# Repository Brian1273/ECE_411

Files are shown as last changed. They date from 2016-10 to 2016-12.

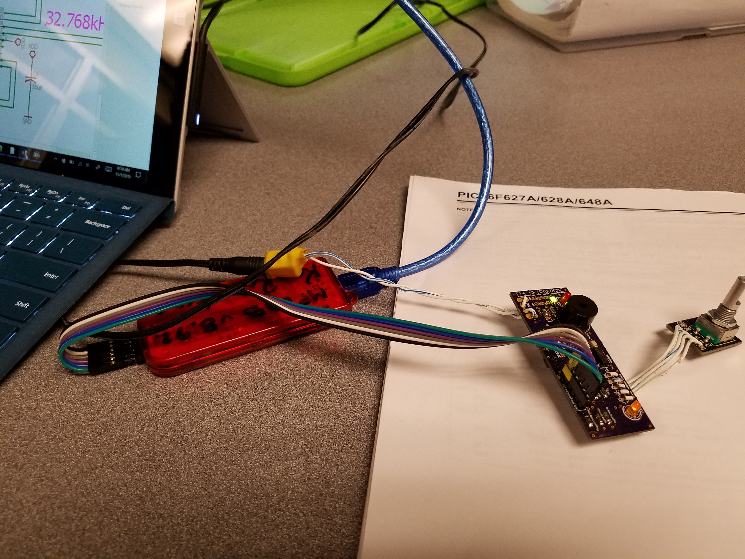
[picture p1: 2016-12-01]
Project_Metronome/Images/Progress_Images/test_debug.jpg

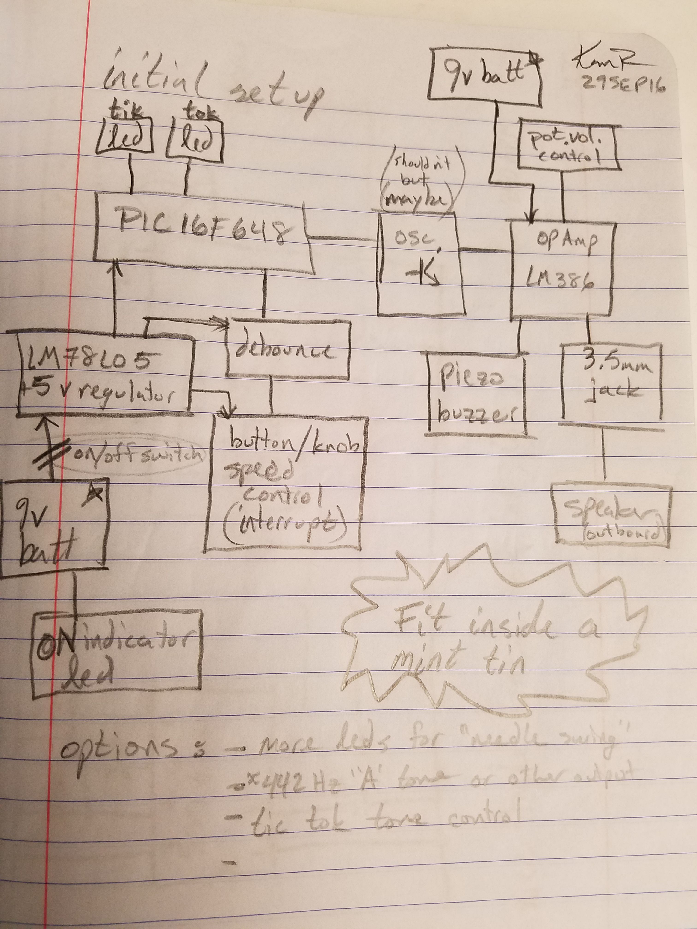
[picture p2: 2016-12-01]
Project_Metronome/Images/Progress_Images/block_diagram_concept.jpg

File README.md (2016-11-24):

# ECE_411

ECE411 practicum project:  Metronome.

Objectives:

Use an input device such as a sensor
Use an output device such as an LED or sound emitter
Use a microcontroller to manager the signals.

All of these items are combined to create a metronome that is capable of pace setting and provides visual and auditory feedback.

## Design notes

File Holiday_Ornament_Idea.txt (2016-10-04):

Kam Robertson
October 2016
Holiday Ornament or Trinket

What holiday is complete without a theme shaped pcb with flahing lights and a piezo soundtrack?

Use the microcontroller to flash as many led's as posible on a 9v battery in several pleasing 
themes and play lovely piezo electric music to match.
Add a safety pin and it is a perfect complement to the madatory sweater!

This is the perfect cliche holiday project.

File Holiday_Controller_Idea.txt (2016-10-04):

Kam Robertson
October 2016
Holiday Light Controller

Use a microcontroller to control a relay that controls power to a holiday string lighting.
Use a conventional plug strip and some metal seperation inside for the low voltage.
Input a signal to the microcontroller via a debounced dc switch to select the theme.
Output the signals to several transistors controlling several 5vdc 120vac 2amp relays (optocoupler?)
The controller will then turn the relays on and off in several pleasing themes.
Allow for manual shut down with the power off switch on the plug strip
Provide power to the contoller and support hardware from 120vac

I don't have a good small circuit worked out that has been tested to provide usable power from 120vac
May need to use a pre-packaged power supply.

This would be a nice practical holiday project.

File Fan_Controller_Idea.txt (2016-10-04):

Kam Robertson
October 2016
Bathroom Fan Controller

Use a microcontroller to control a relay that controlls power to a bathroom fart fan.
Input a signal to the microcontroller via a conventional 120v light switch (optocoupler)
Output the signal to a transistor controlling the 5vdc 120vac 2amp relay (optocoupler?)
The controller will then turn on the relay and begin a 20-30 minute countdown 
to shut off of the relay and fan.  then do so.
Allow for manual shut down of the relay via a second cyling of the light switch.
Provide power to the contoller and support hardware from 120vac
Put the whole thing on a tiny pcb with some led's to indicate life and labeled 14gauge wires hanging out
Package it with nice thick adhesive shrink tube. (1000v rated)

This would be a nice practical project that is installable and invisible in existing construction.
I want at least several and know at least one other person who doea too!

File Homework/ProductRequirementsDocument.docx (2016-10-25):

Product Requirements Document

Project MetroKnome

Revision Date: 10/24/2016

Team #: 14

Team Members:

Saly Hakkoum

Kam Robertson

Brian Dunn

Kyle Johnson

A. Purpose/summary

Visual and aural output variable timing device that can be used as a baseline for a specific pace.

B. Needs/objective/background:

Inexpensive solution to provide a pace setting device for a multitude of uses that incorporates an input mechanism to set the desired pace along with an output mechanism to confirm the desired pace.

Minimal instructions necessary beyond product description, easy to use such that a 5 year old human child can operate within 1 minute.

C. Functionality

Input device to change the pace (beats per minute).

Output device to produce auditory indicator of the passage of the set time period.

Output device to produce visual indicator of passage of the set time period.

Programmable.

D. Performance

30 to 230 bpm in 20 beat increments to provide a variety of slow, medium, and fast tempos.

E. Competition/Intended Market

Competition is substantial, therefore a low cost solution is needed.

The primary market is musicians for time synchronization, however the device will enable anyone needing a visual/aural pace setting device. An example includes medical training centers who use the device to optimize the timing of chest compressions during cardiopulmonary resuscitation on a manikin.

F. Safety/Environmental

Intrinsically safe, dry, at room temperature.

G. Economic

The total parts and manufacturing costs cannot exceed $50 per unit

The development costs should not exceed $250

H. Energy

The system will use an off the shelf 9V battery.

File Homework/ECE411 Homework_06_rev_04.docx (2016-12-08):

ECE411 Homework_6

Test Plan, Revision 2.0

November 23, 2016

Team#14

Kam Robertson

Saly Hakkoum

Brian Dunn

Kyle Johnson

## Introduction

We have designed a metronome to satisfy the practicum requirements of an input device, output device, and microcontroller.

We define metronome as a pace setting device that provides an aural and visual indictor of pace.

A formal definition:

“a mechanical or electrical instrument that makes repeated clicking sounds at an adjustable pace, used for marking rhythm, especially in practicing music.” [1]

To test this, the focus is on the actuators to verify the device is performing the designed function.

## Pretest preparation

1. Ohm board to verify as built assembly meets requirements for system testing.
2. Ensure board has 9V battery installed.

## Test equipment / Test setup and calibration

1. Human of average intelligence, physique, hearing, visual acuity.
2. Multi-meter to perform Ohm test
3. 9V battery

## Systems Test

### Test Case 01 Description

Verify on/off (toggle) switch work, ie does the button turn the device on/off.

### Test Case 01

| Test Writer | Team#14 (Kyle Johnson, Kam Robertson, Saly Hakkoum, Brian Dunn)
| Test case name: | Test Case 01
| Description | Verify on/off (toggle) switch work
| Type | Black Box
| Tester Information
| Name of tester
| Hardware Version | Version 2.0
| Setup | 1. Ohm board to verify as built assembly meets requirements for system testing. 2. Ensure board has 9V battery installed.
Step | Action | Expected Results | Pass | Fail | NA | Comment
1 | Position metronome on flat surface | Device ready for visual observation.
2 | Verify device is at initial state | Observe initial state, OFF
3 | Press power button | The device changes state, visual indications such as lights turn on.
4 | Verify device is in on state | Lights turn on.
5 | Press power button | The device changes state, visual indications such as lights turn off
6 | Verify device is in off state | Lights are off

### Test Case 02 Description

Verify button changes function of metronome.

Lights (LED) flash when button pressed.

### Test Case 02

| Test Writer | Team#14 (Kyle Johnson, Kam Robertson, Saly Hakkoum, Brian Dunn)
| Test case name: | Test Case 02
| Description | Verify button changes function of device
| Type | Black Box
| Tester Information
| Name of tester
| Hardware Version | Version 2.0
| Setup | 1. Ohm board to verify as built assembly meets requirements for system testing. 2. Ensure board has 9V battery installed.
Step | Action | Expected Results | Pass | Fail | NA | Comment
1 | Position metronome on flat surface | Device ready for visual observation.
2 | Verify device is at initial state | Observe initial state, OFF
3 | Press power button | The device changes state, visual indications such as lights turn on.
4 | Verify device is in on state | Lights turn on.
5 | Press function button | Lights flash when button pressed
6 | Observe change in function | Verify function changes when button pressed

### Test Case 03 Description

Verify button changes function of device (modes)

1) Lights (LED) flash when button pressed once. Muted 4/4 time
2) Lights (LED) flash when button pressed twice in addition to sound (beep) matching up with each LED flash. 4/4 time
3) “ “ 2/4 time (BEEP,beep…)
4) “ “ 2/3 time (BEEP, beep, beep…)
5) “ “ 3/4 time (BEEP, beep, beep, beep…)
6) “ “ 6/8 time (BEEP, beep, beep, beep, beep, beep…)
7) Standby: UUT returns to idle state

### Test Case 03

| Test Writer | Team#14 (Kyle Johnson, Kam Robertson, Saly Hakkoum, Brian Dunn)
| Test case name: | Test Case 03
| Description | Verify button changes function of device (modes)
| Type | Black Box
| Tester Information
| Name of tester
| Hardware Version | Version 2.0
| Setup | 1. Ohm board to verify as built assembly meets requirements for system testing. 2. Ensure board has 9V battery installed.
Step | Action | Expected Results | Pass | Fail | NA | Comment
1 | Position metronome on flat surface | Device ready for visual observation.
2 | Verify device is at initial state | Observe initial state, OFF
3 | Press power button | The device changes state, visual indications such as lights blink once, sound occurs "beep" at initial power on
4 | Verify device is in on state | Lights blink, single beep, no additional sound, UUT idle
5 | Press function button | Lights flash when button pressed once
6 | Observe change in function | The device changes state, visual indication such as lights begin flashing in an alternating sequence (no sound) that coincides with beats per minute
7 | Press function button | Verify function changes when button pressed
8 | Observe change in function | The device changes state, visual indication such as lights begin alternating sequence along with sound to accompany each light flash that coincides with beats per minute
9 | Press function button | Verify function changes when button pressed
10 | Observe change in function | The device changes state, visual indication such as lights begin alternating sequence along with sound to accompany each light flash that coincides with beats per minute
11 | Press function button | Verify function changes when button pressed
12 | Observe change in function | The device changes state, visual indication such as lights begin alternating sequence along with sound to accompany each light flash that coincides with beats per minute
13 | Press function button | Verify function changes when button pressed
14 | Observe change in function | The device changes state, visual indication such as lights begin alternating sequence along with sound to accompany each light flash that coincides with beats per minute
15 | Press function button | Verify function changes when button pressed
16 | Observe change in function | The device changes state, visual indication such as lights begin alternating sequence along with sound to accompany each light flash that coincides with beats per minute
17 | Press function button | UUT returns to idle state
18 | Observe change in function | UUT returns to idle state, no lights, sound.

### Test Case 04 Description

Verify rotary encoder function of device

Verify UUT tempo changes (increases) with clockwise rotation of rotary encoder

Verify UUT tempo changes (decreases) with counter-clockwise rotation of rotary encoder

### Test Case 04

| Test Writer | Team#14 (Kyle Johnson, Kam Robertson, Saly Hakkoum, Brian Dunn)
| Test case name: | Test Case 03
| Description | Verify rotary encoder function of device
| Type | Black Box
| Tester Information
| Name of tester
| Hardware Version | Version 2.0
| Setup | 1. Ohm board to verify as built assembly meets requirements for system testing. 2. Ensure board has 9V battery installed.
Step | Action | Expected Results | Pass | Fail | NA | Comment
1 | Position metronome on flat surface | Device ready for visual observation.
2 | Verify device is at initial state | Observe initial state, OFF
3 | Press power button | The device changes state, visual indications such as lights blink once, sound occurs "beep" at initial power on
4 | Verify device is in on state | Lights blink, single beep, no additional sound, UUT idle
5 | Press function button | Lights flash when button pressed once
6 | Observe change in function | The device changes state, visual indication such as lights begin flashing in an alternating sequence (no sound) that coincides with beats per minute
7 | Press function button | Verify function changes when button pressed
8 | Observe change in function | The device changes state, visual indication such as lights begin alternating sequence along with sound to accompany each light flash that coincides with beats per minute
9 | Turn Rotary Encoder (clockwise) | UUT exhibits tempo increase (light sequence and sound sequence)
10 | Observe change in function | Verify UUT tempo changes (increases) with clockwise rotation of rotary encoder
11 | Turn Rotary Encoder (counter-clockwise) | UUT exhibits tempo decrease (light sequence and sound sequence)
12 | Observe change in function | Verify UUT tempo changes (decreases) with counter-clockwise rotation of rotary encoder

## Citations

1) (Dictionary.com "metronome, 2016)

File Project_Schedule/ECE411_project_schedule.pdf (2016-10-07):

ECE411_Practicum | Oct 7, 2016
PSU | http://

Project manager
Project dates | Sep 13, 2016 - Dec 9, 2016
Completion | 0%
Tasks | 14
Resources | 0

Name | Begin date | End date
Conception | 9/13/16 | 10/5/16
Teams Formed, projects analyzed | 9/13/16 | 9/19/16
Research | 9/29/16 | 10/5/16
Teams formed, project decide | 9/30/16 | 10/7/16
Parts Identification and Preliminary schematic | 10/3/16 | 10/13/16
Prototyping | 10/5/16 | 10/18/16
Preliminary Schematic | 10/17/16 | 10/21/16
Preliminary layout done | 10/24/16 | 10/25/16
Layout | 10/26/16 | 11/3/16
Board fabbed | 11/4/16 | 11/11/16
Boards to manufacturing | 11/14/16 | 11/18/16
Assembly and Test | 11/14/16 | 11/25/16
Debug | 11/14/16 | 11/25/16
Demonstrations | 11/30/16 | 12/8/16
ECE411_Practicum | Oct 7, 2016
Tasks | 2

## Gantt Chart

3

Name | Begin ... | End date
Conception | 9/13/16 10/5/16
Teams formed, project decide | 9/30/16 10/7/16

Parts Identification and Preliminary sche... 10/3/16 10/13/16

Prototyping | 10/5/16 10/18/16
Preliminary Schematic | 10/17/1610/21/16
Preliminary layout done | 10/24/1610/25/16
Layout | 10/26/1611/3/16
Board fabbed | 11/4/16 11/11/16
Boards to manufacturing | 11/14/1611/18/16
Assembly and Test | 11/14/1611/25/16
Debug | 11/14/1611/25/16
Demonstrations | 11/30/1612/8/16
October 2016 | November 2016 | December 2016
Week 41 | Week 42 | Week 43 | Week 44 | Week 45 | Week 46 | Week 47 | Week 48 | Week 49 | Week 50 | Week 51
10/2/16 | 10/9/16 | 10/16/16 | 10/23/16 | 10/30/16 | 11/6/16 | 11/13/16 | 11/20/16 | 11/27/16 | 12/4/16 | 12/11/16

## Resources Chart

4

Name | Default role
October 2016 | November 2016 | December 2016
Week 41 | Week 42 | Week 43 | Week 44 | Week 45 | Week 46 | Week 47 | Week 48 | Week 49 | Week 50 | Week 51
10/2/16 | 10/9/16 | 10/16/16 | 10/23/16 | 10/30/16 | 11/6/16 | 11/13/16 | 11/20/16 | 11/27/16 | 12/4/16 | 12/11/16

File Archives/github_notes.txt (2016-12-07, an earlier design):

After cloning repository (to remote desktop) and launching power shell (if windows based OS):

From power shell:

1.  move file to new location (mv)
2.  git add <new location>
3.  git rm <old location>
4.  git commit -m "comments"
5.  git status // last chance to make sure you got everything squared away
6.  git push

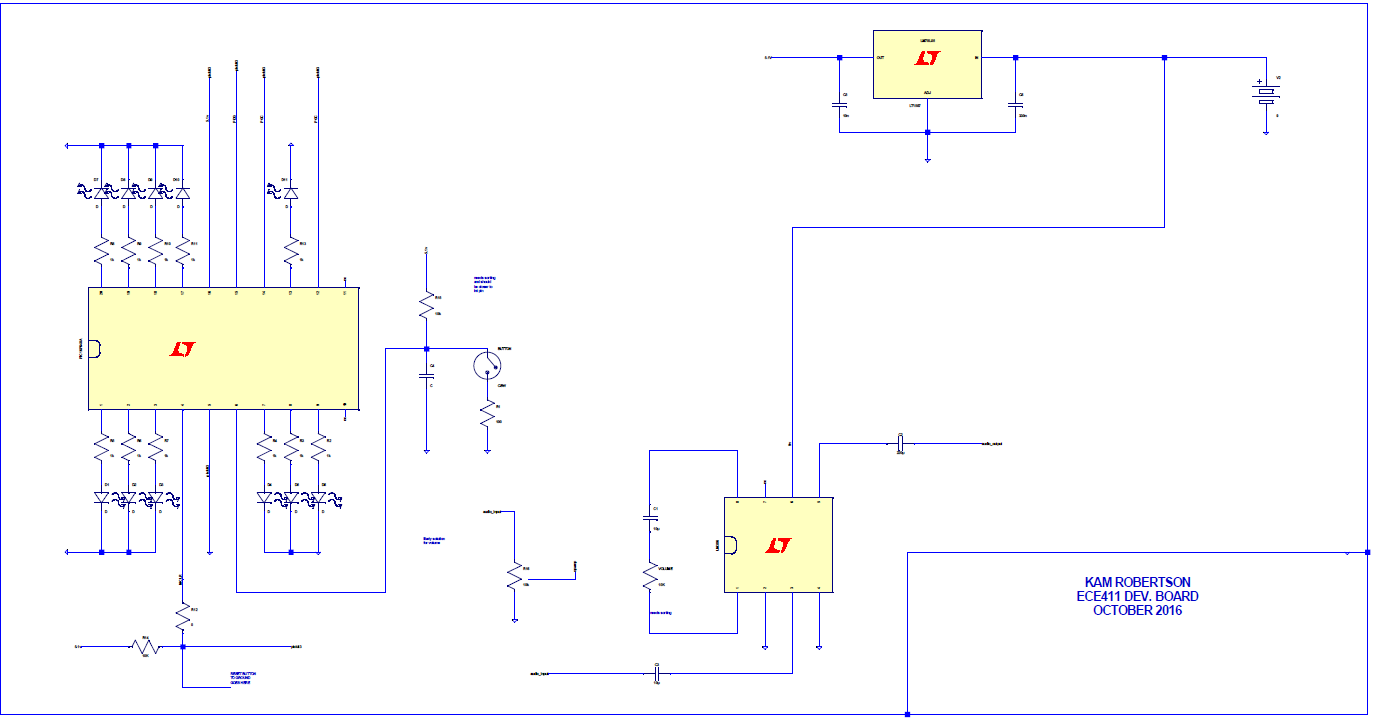
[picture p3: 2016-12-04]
Project_Metronome/Images/Progress_Images/ltspice_schematic_image.PNG

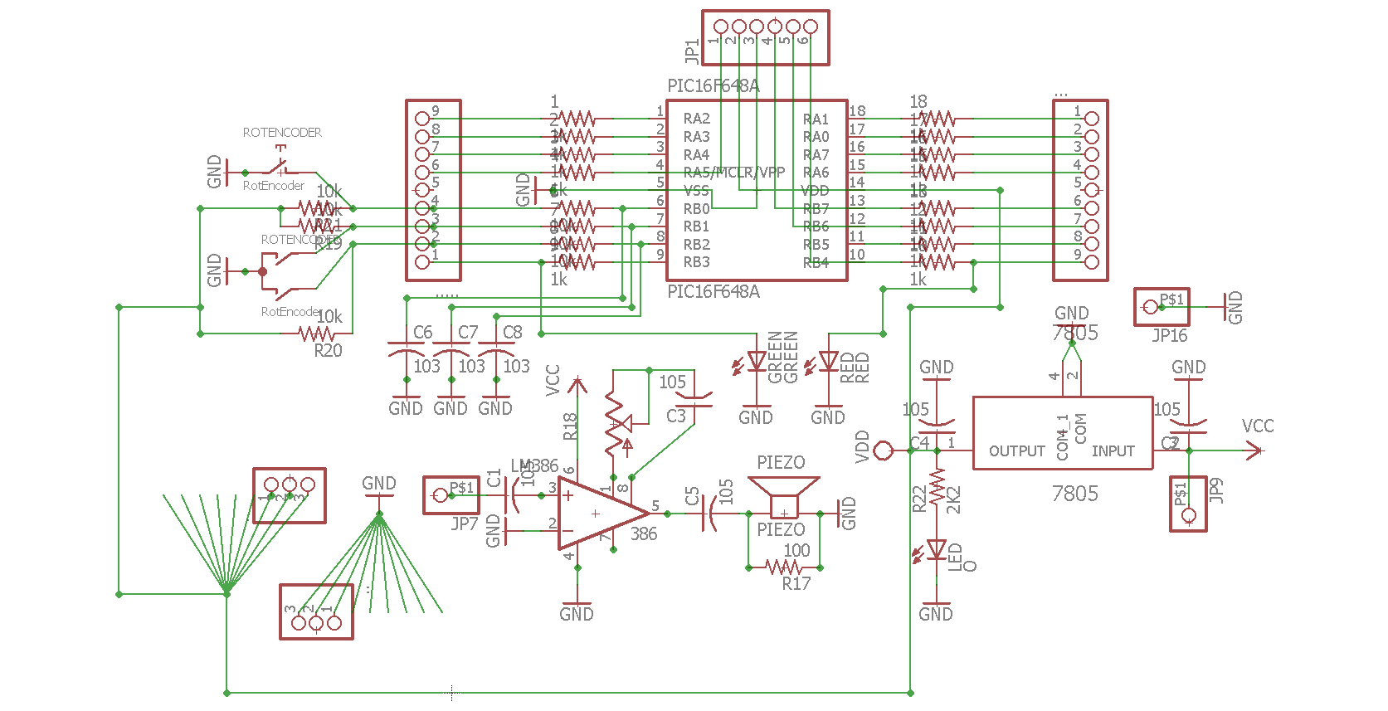
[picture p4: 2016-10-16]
Project_Metronome/Images/Schematic_rev_01.PNG

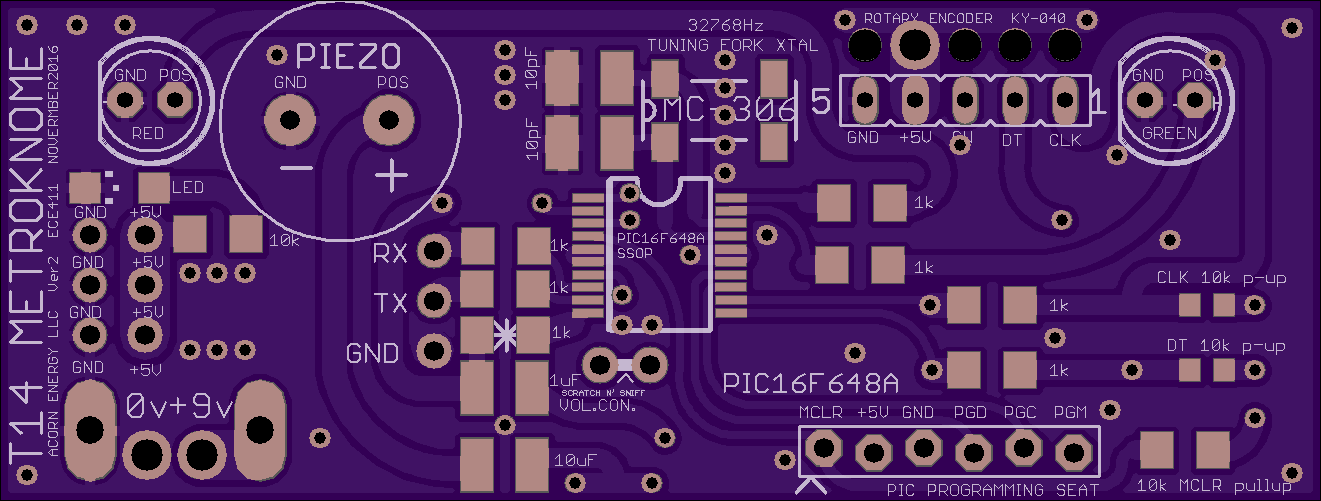
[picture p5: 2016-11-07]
Project_Metronome/Schematics/41fce9585ad315832eba177b4957e8e9.png

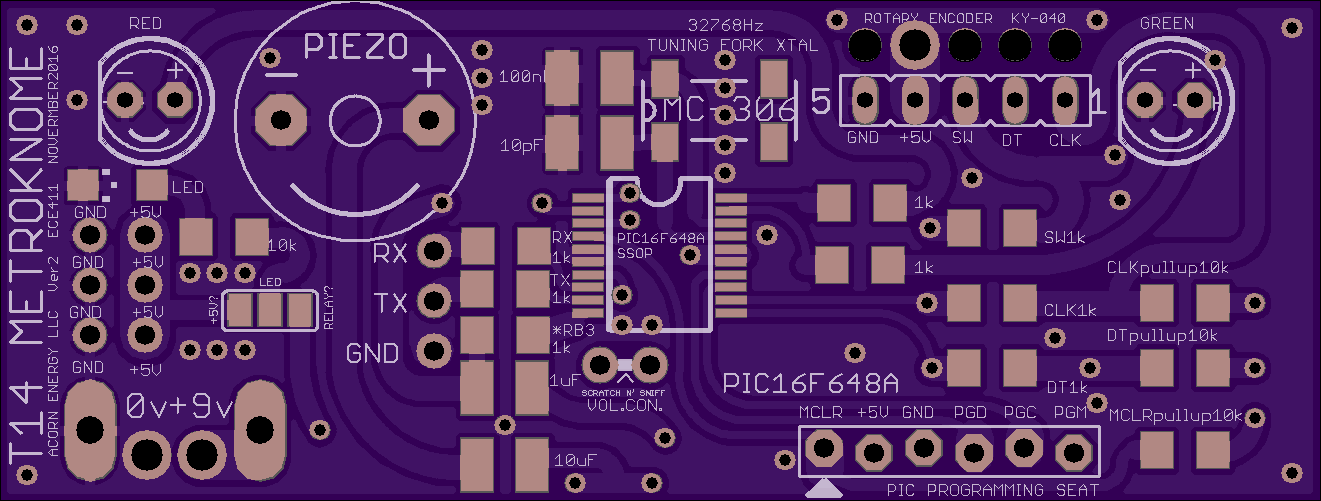
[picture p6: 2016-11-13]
Project_Metronome/Schematics/f53ea1d65c769cc9e6893a54a9820326.png

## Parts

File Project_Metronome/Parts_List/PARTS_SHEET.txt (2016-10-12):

COST SHEET
KAM ROBERTSON
ECE411 08OCT2016

LM386						

PIC16F648A					

LM78L05						

ELECTROLYTIC CAPACITOR		

CERAMIC CAPACITOR			

1206 RESISTOR				

AXIAL RESISTOR				

PERFBOARD					

ZIF SOCKET 18PIN					

DIP8 SOCKET					

2x40 STRAIGHT HEADER		

1x40 STRAIGHT HEADER		

1x40 NINETY DEGREE HEADER

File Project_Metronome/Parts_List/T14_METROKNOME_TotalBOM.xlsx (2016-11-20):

 | 14 METROKNOME ECE411
 | TOTAL COST & BOM SHEET
 | KAM ROBERTSON
 | 2016-11-01
 | COST PER PERSON |  | $55.26
AMOUNT | DESCRIPTION | SOURCE | UNITCOST | TOTAL
1.00 | extruded aluminum enclosure | custom | $6.93 | $6.93
0.25 | fab shop v2 board shop | oshpark | $13.20 | $3.30
1.00 | PIC16f648a ssop 20pin | mouser | $2.60 | $2.60
1.00 | 0.5k 1206 resistor | mouser | $0.10 | $0.10
3.00 | 10k 1206 resistor | mouser | $0.10 | $0.30
7.00 | 1k 1206 resistor | mouser | $0.10 | $0.70
1.00 | 100nF 1206 capacitor | mouser | $0.10 | $0.10
2.00 | 10pf 1206 capacitor | mouser | $0.10 | $0.20
4.00 | 10uf 1206 capacitor | mouser | $0.10 | $0.40
2.00 | 1uf 1206 capacitor | mouser | $0.10 | $0.20
3.00 | 10nf capacitor | mouser | $0.10 | $0.30
1.00 | lm386 soic | mouser | $0.85 | $0.85
1.00 | 78l05 sot89 | mouser | $0.41 | $0.41
0.25 | 6 pin header | mouser | $2.29 | $0.57
1.00 | 9 volt battery | mouser | $2.37 | $2.37
1.00 | 9 volt battery clip | mouser | $0.36 | $0.36
2.00 | 5mm thru hole led | mouser | $0.17 | $0.34
1.00 | piezo buzzer no int. osc. | mouser | $0.84 | $0.84
1.00 | 1206 led | mouser | $0.17 | $0.17
1.00 | pec-11 w/switch and 24detent | mouser | $1.68 | $1.68
1.00 | on/off toggle switch | mouser | $2.25 | $2.25
5.00 | stranded teflon wire | mouser | $0.53 | $2.65
1.00 | mc-306 32.768 tuning fork xtal | mouser | $0.51 | $0.51
1.00 | pnp transistor sot89 | mouser | $0.39 | $0.39
1.00 | npn transistor sot23 | mouser | $0.10 | $0.10
0.25 | T14 PROTO DEV. BOARD | custom | $76.97 | $19.24
0.25 | fab shop v1 pcb | oshpark | $13.25 | $3.31
0.25 | parts for v1 pcb | mouser | $16.32 | $4.08
 | COST PER PERSON |  |  | $55.26

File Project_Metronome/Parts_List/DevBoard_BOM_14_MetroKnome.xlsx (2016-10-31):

14 METROKNOME ECE411
DEV. BOARD COST SHEET
BOM
KAM ROBERTSON
2016-10-01
 | AMOUNT | DESCRIPTION | SOURCE | UNITCOST | TOTAL
 | 1.00 | DEV. BOARD thru-hole |  | $37.55 | $37.55
 | 1.00 | 10k 1t pot | mouser | $0.40 | $0.40
 | 12.00 | 3mm led red | mouser | $0.20 | $2.40
 | 0.25 | 6 pin right angle header | mouser | $2.29 | $0.57
 | 2.00 | 2 screw terminal block | mouser | $1.03 | $2.06
 | 1.00 | PIC16f648a | mouser | $2.36 | $2.36
 | 1.00 | lm386 | mouser | $0.97 | $0.97
 | 1.00 | 78l05 | mouser | $0.34 | $0.34
 | 2.00 | 10k resistor | mouser | $0.10 | $0.20
 | 13.00 | 1k resistor | mouser | $0.10 | $1.30
 | 1.00 | 1nf capacitor | mouser | $0.10 | $0.10
 | 1.00 | 1uf capacitor | mouser | $0.10 | $0.10
 | 4.00 | electrolytic capacitor | mouser | $0.10 | $0.40
 | 1.00 | microbutton | mouser | $0.22 | $0.22
 | 1.00 | perfboard | estimate | $1.00 | $1.00
 | 1.00 | 18 pin zif socket | mouser | $19.77 | $19.77
 | 1.00 | female dc plug | mouser | $0.85 | $0.85
 | 1.00 | male dc jack | mouser | $0.94 | $0.94
 | 1.00 | 9v battery | mouser | $2.37 | $2.37
 | 1.00 | 9v battery connector | mouser | $0.36 | $0.36
 | 1.00 | piezo buzzer no int. osc. | mouser | $0.84 | $0.84
 | 1.00 | OP AMP BUZZER BOARD |  | $5.33 | $5.33
 | 1.00 | 2 screw terminal block | mouser | $1.03 | $1.03
 | 3.00 | teflon wire | mouser | $0.53 | $1.59
 | 0.50 | perfboard | estimate | $1.00 | $0.50
 | 1.00 | lm386 | mouser | $0.97 | $0.97
 | 1.00 | piezo buzzer no int. osc. | mouser | $0.84 | $0.84
 | 3.00 | 1uf capacitor | mouser | $0.10 | $0.30
 | 1.00 | 10uf capacitor | mouser | $0.10 | $0.10
 | 2.00 | XTAL BOARD |  | $5.12 | $10.24
 | 1.00 | mc-306 32.768kHz xtal | mouser | $0.51 | $0.51
 | 2.00 | 10pf capacitor | mouser | $0.10 | $0.20
 | 1.00 | sot8 -> dip8 adapter board | mouser | $3.05 | $3.05
 | 2.00 | teflon wire | mouser | $0.53 | $1.06
 | 3.00 | shrink tube | estimate | $0.10 | $0.30
 | 2.00 | BJT RELAY BOARD |  | $3.53 | $7.06
 | 1.00 | npn bjt | mouser | $0.17 | $0.17
 | 1.00 | pnp bjt | mouser | $0.19 | $0.19
 | 1.00 | 10k resistor | mouser | $0.10 | $0.10
 | 2.00 | 1k resisor | mouser | $0.10 | $0.20
 | 0.25 | perfboard | estimate | $1.00 | $0.25
 | 4.00 | teflon wire | mouser | $0.53 | $2.12
 | 5.00 | shrink tube | estimate | $0.10 | $0.50
 | 2.00 | ROTARY ENCODER BOARD |  | $5.73 | $11.46
 | 1.00 | pec-11 w/switch w/24detent | mouser | $1.68 | $1.68
 | 1.00 | pec-11 breakout | estimate | $0.00 | $0.00
 | 3.00 | 10k resistors | mouser | $0.10 | $0.30
 | 3.00 | 1k resistor | mouser | $0.10 | $0.30
 | 3.00 | 10nF capacitor | mouser | $0.10 | $0.30
 | 5.00 | ptfe wire | mouser | $0.53 | $2.65
 | 5.00 | shrink tube | estimate | $0.10 | $0.50
 |  | TOTAL PRE-PCB COST |  |  | $71.64

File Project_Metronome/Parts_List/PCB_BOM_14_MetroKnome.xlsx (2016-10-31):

14 METROKNOME ECE411
pre-PCB COST SHEET
current estimate BOM
KAM ROBERTSON
2016-10-01
 | AMOUNT | DESCRIPTION | SOURCE | UNITCOST | TOTAL
 | 4.00 | PROTOBOARD thru-hole |  | $24.73 | $98.92
 | 4.00 | extruded aluminum enclosure |  | $6.93 | $27.72
 | 3.00 | OshPark board shop | mouser | $4.42 | $13.26
 | 1.00 | PIC16f648a ssop 20pin | mouser | $2.60 | $2.60
 |  | 10k 1206 resistor | mouser | $0.10 | $0.10
 |  | 1k 1206 resistor | mouser | $0.10 | $0.10
 | 2.00 | 10pf 1206 capacitor | mouser | $0.10 | $0.20
 |  | 10uf 1206 capacitor | mouser | $0.10 | $0.10
 |  | 1uf 1206 capacitor | mouser | $0.10 | $0.10
 | 3.00 | 10nf capacitor | mouser | $0.10 | $0.30
 | 1.00 | lm386 soic | mouser | $0.85 | $0.85
 | 1.00 | 78l05 so89 | mouser | $0.41 | $0.41
 | 0.25 | 6 pin right angle header | mouser | $2.29 | $0.57
 | 1.00 | 9 volt battery | mouser | $2.37 | $2.37
 | 1.00 | 9 volt battery clip | mouser | $0.36 | $0.36
 | 2.00 | 5mm thru hole led | mouser | $0.17 | $0.34
 | 1.00 | piezo buzzer no int. osc. | mouser | $0.84 | $0.84
 | 1.00 | 1206 led | mouser | $0.17 | $0.17
 | 1.00 | pec-11 w/switch and 24detent | mouser | $1.68 | $1.68
 | 5.00 | teflon wire | mouser | $0.53 | $2.65
 | 1.00 | mc-306 32.768 tuning fork xtal | mouser | $0.51 | $0.51
 |  | TOTAL PRE-PCB COST |  |  | #REF!

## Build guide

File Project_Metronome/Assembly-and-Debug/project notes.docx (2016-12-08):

Metronome ECE 411 project notes:

PWM mode generation with Timer 2

THE FOLLOWING STEPS SHOULD BE TAKEN WHEN CONFIGURING THE CCP MODULE FOR PWM OPERATION:

1. SET THE PWM PERIOD BY WRITING TO THE PR2 REGISTER.
2. SET THE PWM DUTY CYCLE BY WRITING TO THE CCPR1L REGISTER AND CCP1CON<5:4> BITS
3. MAKE THE CCP1 PIN AN OUTPUT BY CLEARING THE TRISB<3> BIT.
4. SET THE TMR2 PRESCALE VALUE AND ENABLE TIMER2 BY WRITING TO T2CON.

Registers used:

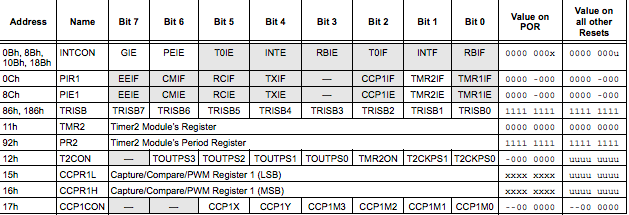
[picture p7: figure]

Calculation Equations:

PWM output based on previous calculations:

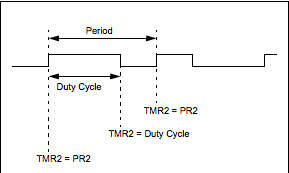
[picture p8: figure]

PWM block diagram:

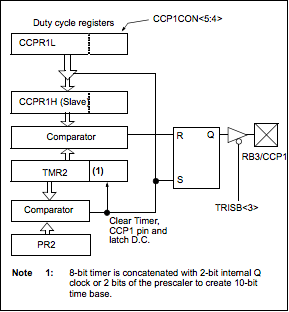
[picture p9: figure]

Testing: Changing the frequency calculations should change the tone of the Pizzo

Resources:

Google search

PIC16F648A data sheet

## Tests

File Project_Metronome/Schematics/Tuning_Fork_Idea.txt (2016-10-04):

Kam Robertson
October 2016
Electronic Tuning Fork

Use a microcontroller to output to a speaker or piezo buzzer a single tone in half steps through four octaves
This seems tricky to me because the software and hardware will have to be tuned precisly,
probably via some external potentiometers on analog inputs.
Use a button or rotary switch to select the tone and display on a 3 digit display

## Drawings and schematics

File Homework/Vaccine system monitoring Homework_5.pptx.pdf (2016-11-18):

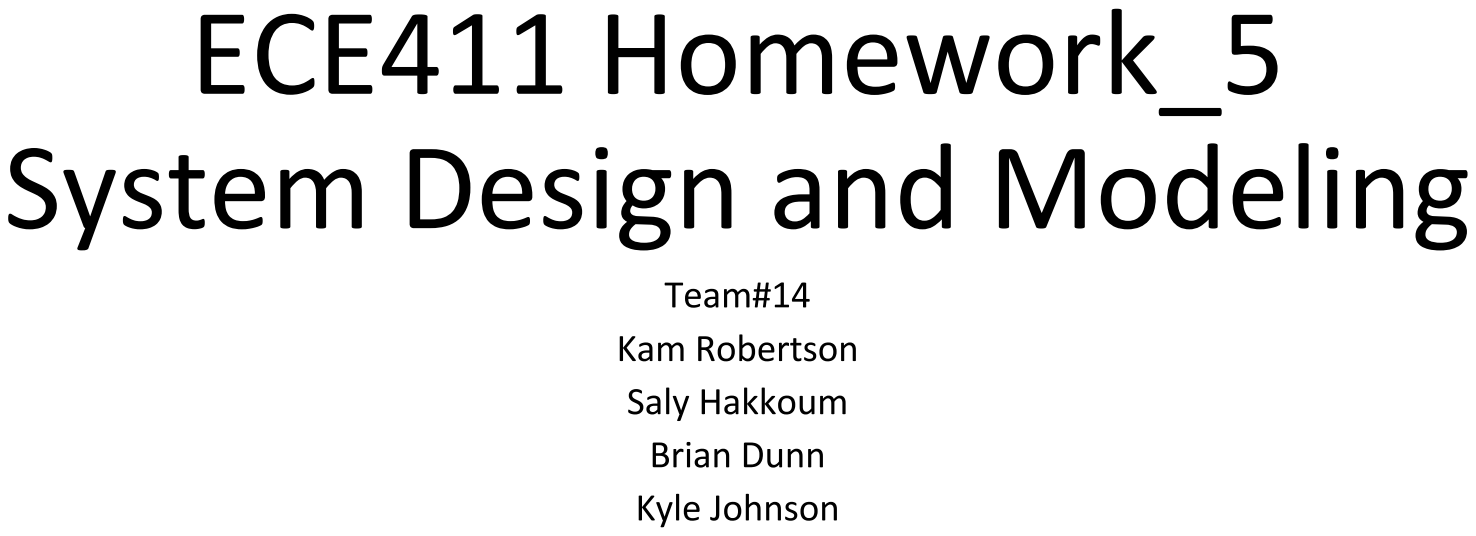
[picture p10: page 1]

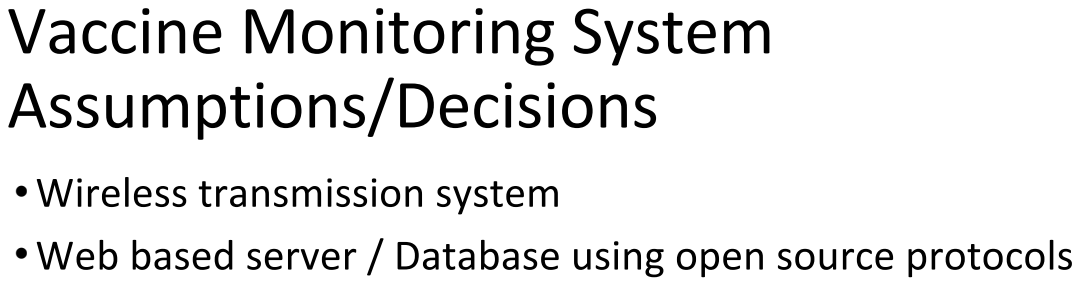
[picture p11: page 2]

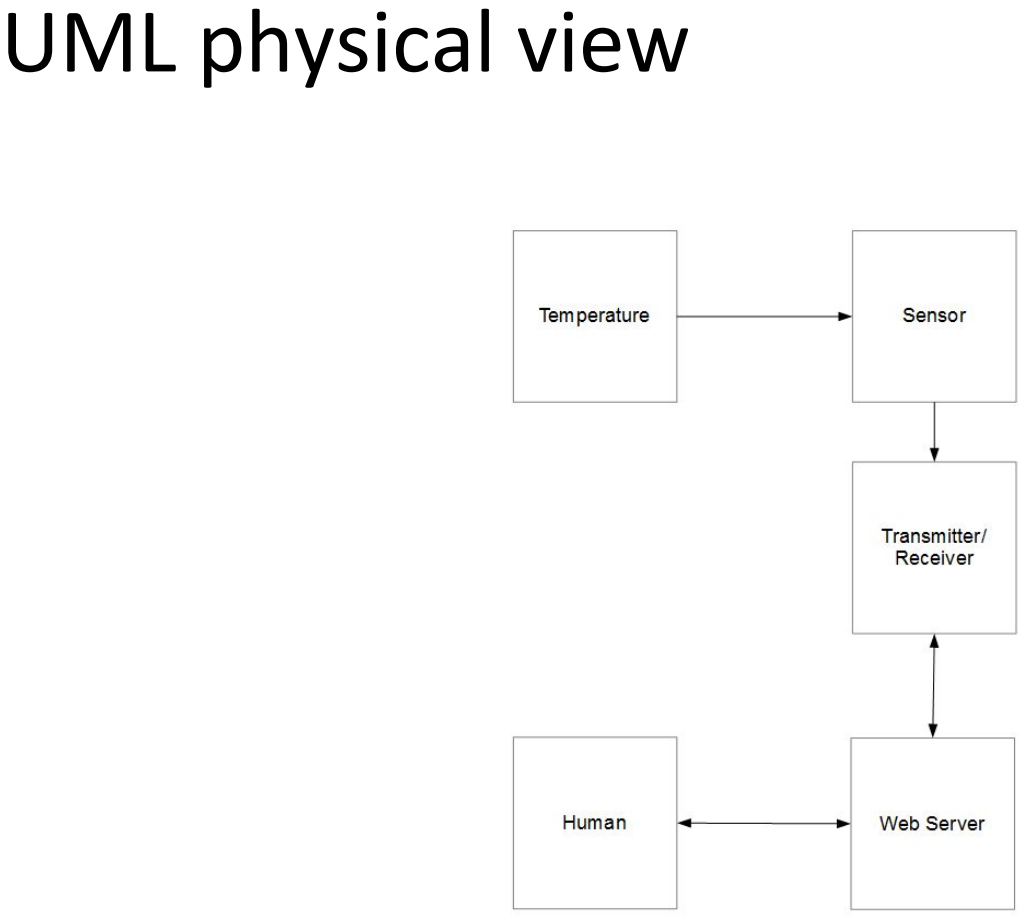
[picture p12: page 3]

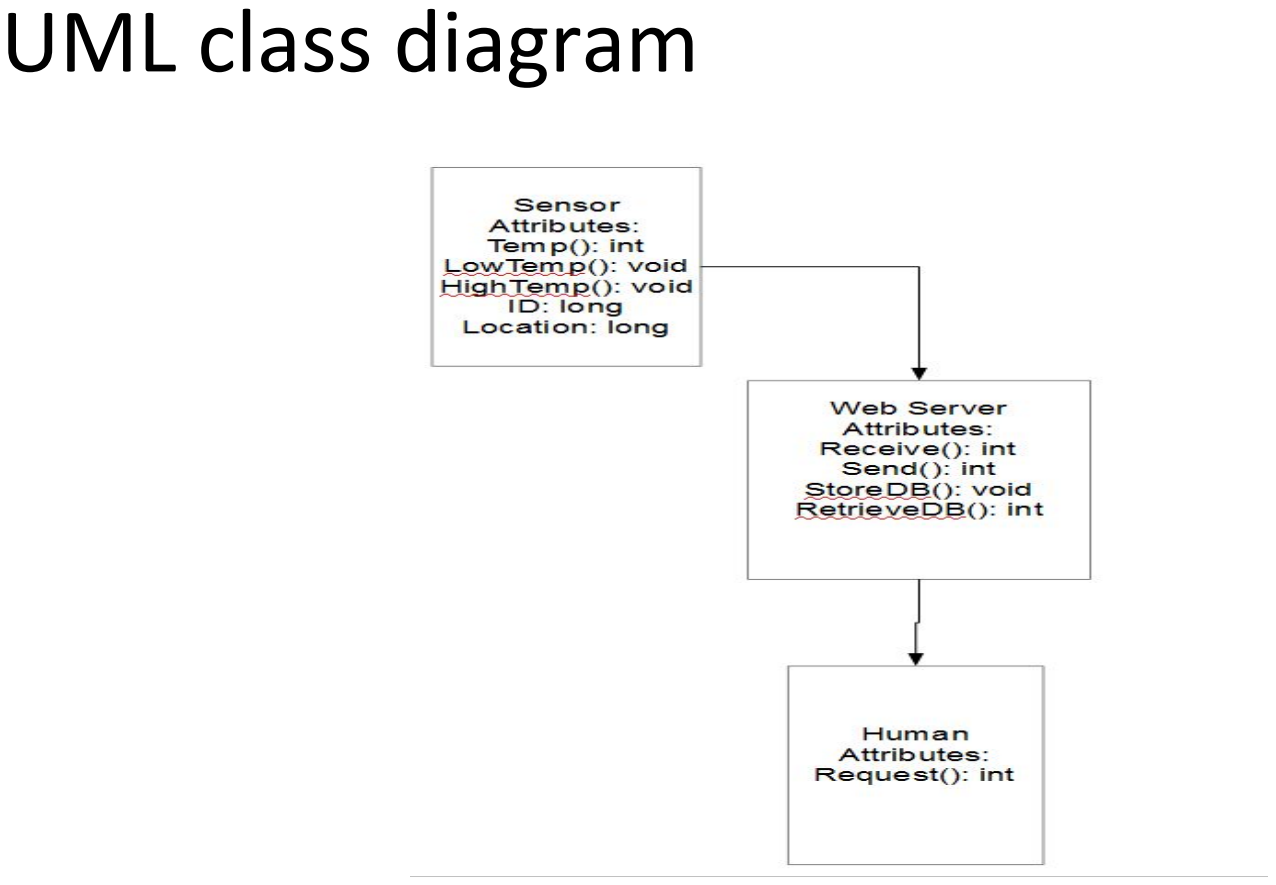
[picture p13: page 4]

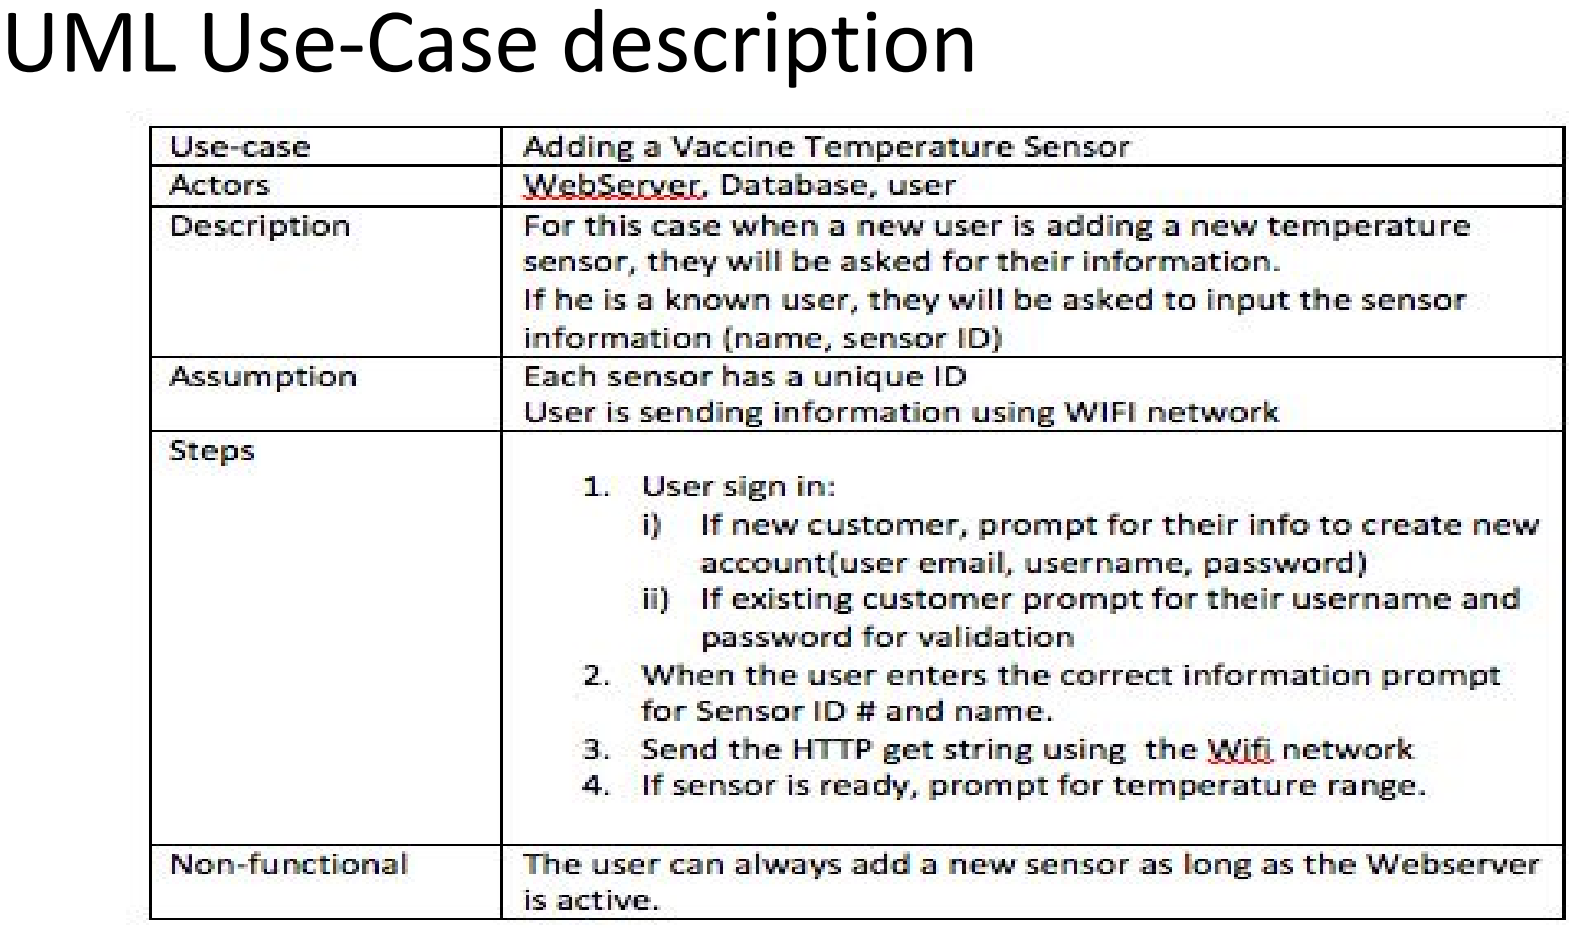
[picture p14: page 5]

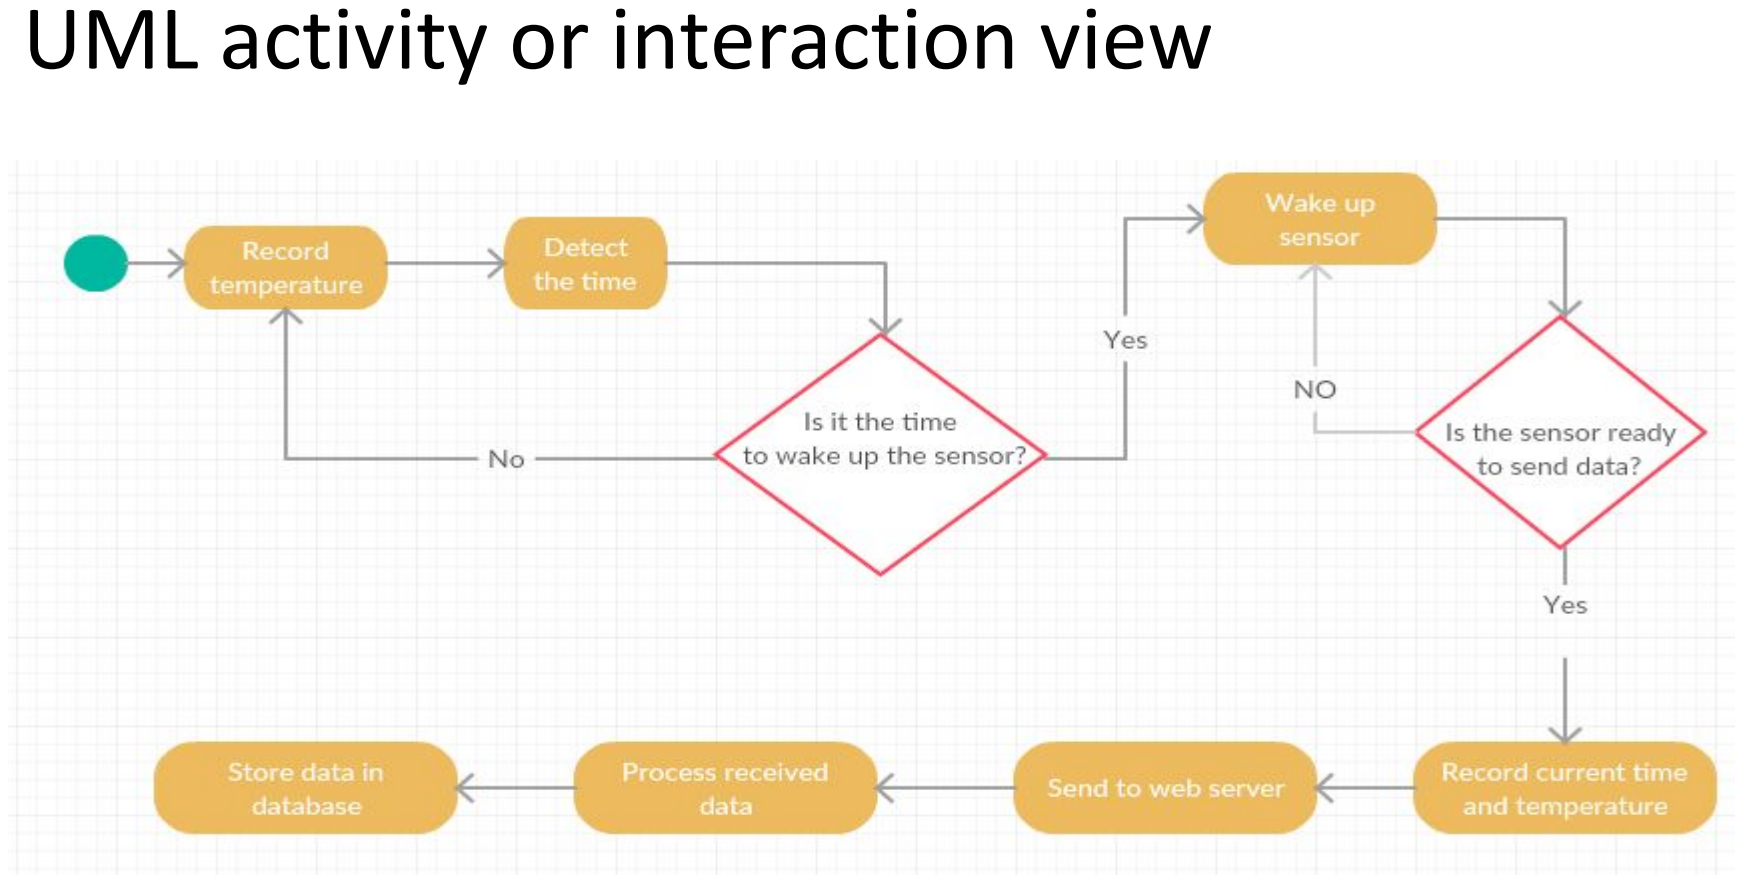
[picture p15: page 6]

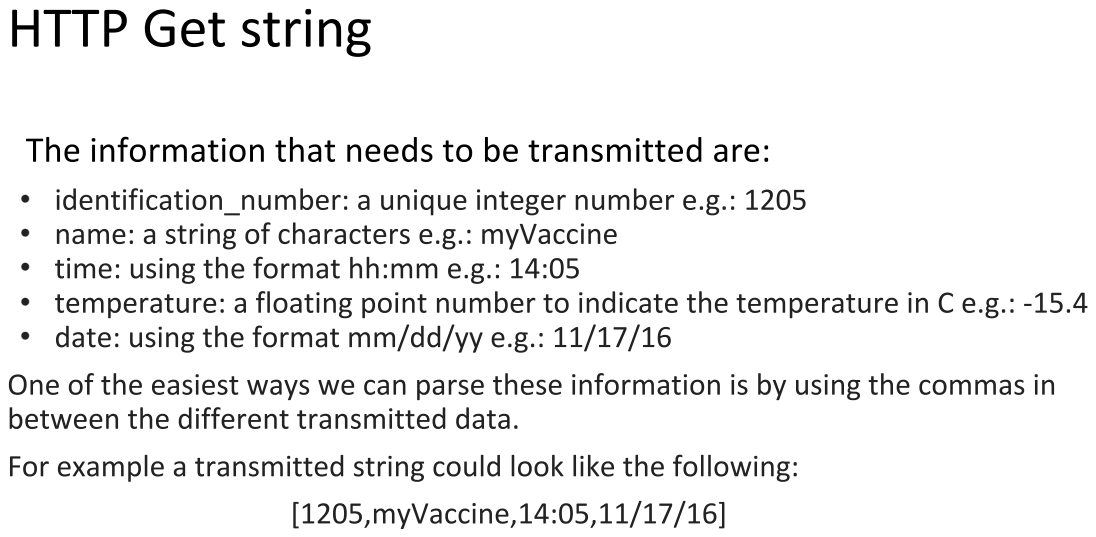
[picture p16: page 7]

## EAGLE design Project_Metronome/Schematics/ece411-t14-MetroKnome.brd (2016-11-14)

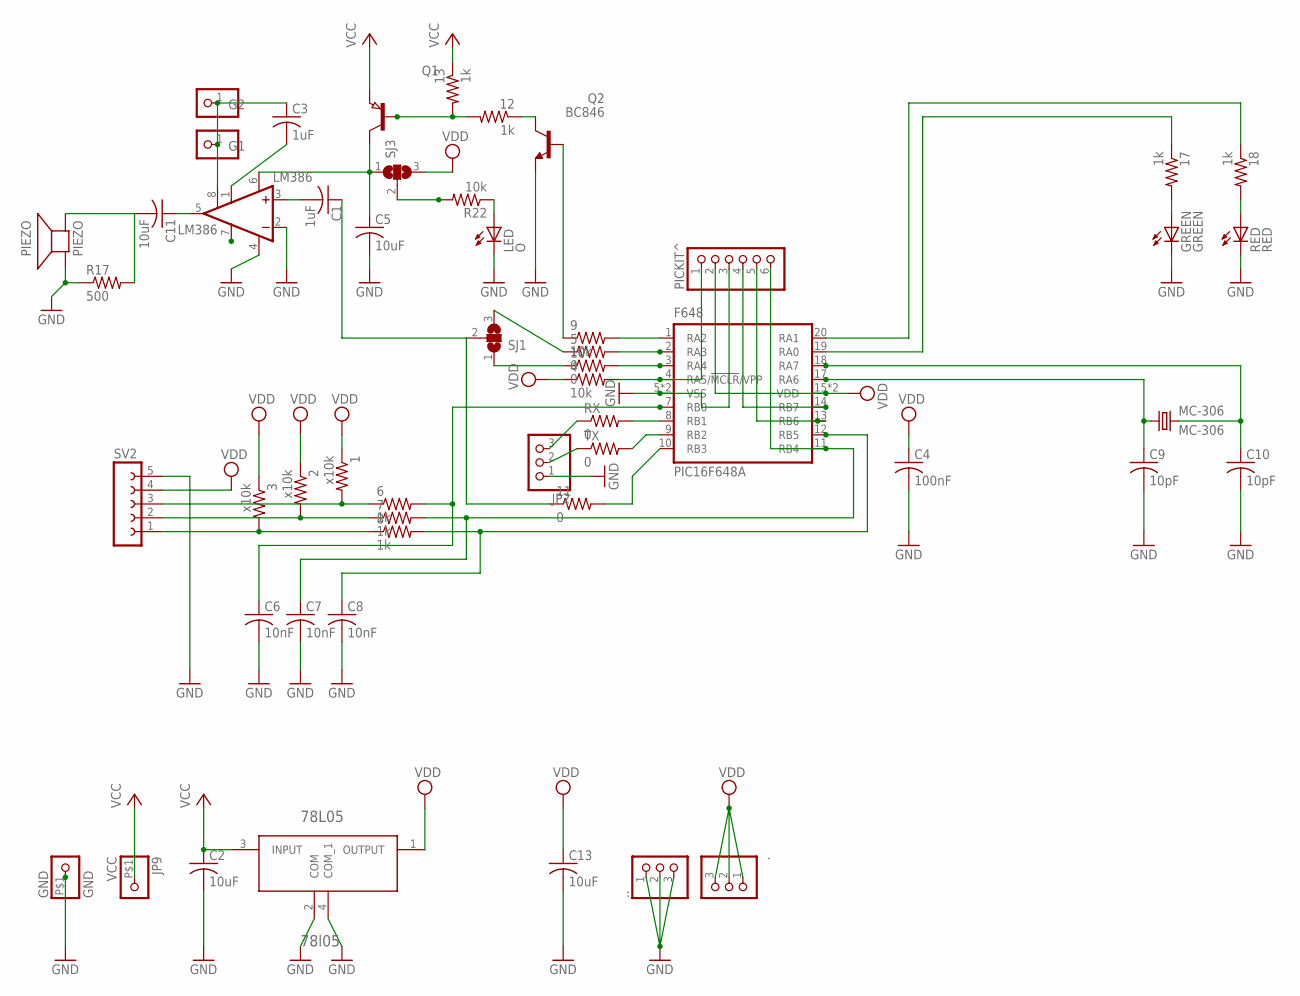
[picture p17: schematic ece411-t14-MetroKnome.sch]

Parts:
1, 2, 3: x10k; R1206
4, 9: 10k; R1206
5, 10: 0; R0603
6, 7, 8, 12, 13, 17, 18: 1k; R1206
11: 0; R1206
78L05: 78l05; SOT150P400X160-4N
., ..: PINHD-1X3CB; 1X03-CLEANBIG
C1, C3: 1uF; C1210
C2, C5, C11, C13: 10uF; C1210
C4: 100nF; C1210
C6, C7, C8: 10nF; C1210
C9, C10: 10pF; C1210
F648: PIC16F648A; SSOP20
G1, G2: PINHD-1X1CB; 1X01-CLEANBIG
GND: GND; 1X1-BIGPOGO
GREEN: GREEN; LED5MM
JP2: PINHD-1X3CB; 1X03-CLEANBIG
JP9: VCC; 1X1-BIGPOGO
LED: O; CHIPLED_1206
LM386: LM386; SO08
MC-306: MC-306; MPN MC-306 60.0KHZ 100PPM ,12.5PF
PICKIT^: PINHD-1X6LOCK; 1X06-BIGLOCK
PIEZO: PIEZO; AL60P
Q1: PNP-TRANSISTOR_SOT89; SOT89
Q2: BC846; SOT23
R17: 500; R1206
R22: 10k; R1206
RED: RED; LED5MM
RX: 0; R1206
SJ1, SJ3: SJ2W; SJ_2
SV2: FE05-1
TX: 0; R1206

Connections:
GND: 78L05.2 (COM), 78L05.4 (COM_1), ...1, ...2, ...3, C2.2, C4.2, C5.2, C6.2, C7.2, C8.2, C9.2, C10.2, C13.2, F648.5 (VSS), F648.6 (VSS), GND.P$1, GREEN.K (C), JP2.1, LED.C, LM386.2 (-IN), LM386.4 (GND), PICKIT^.3, PIEZO.2 (-), Q2.2 (E), R17.1, RED.K (C), SV2.5
unnamed: 9.2, F648.1 (RA2)
unnamed: C3.2, LM386.1 (GAIN)
unnamed: 9.1, Q2.1 (B)
unnamed: 5.2, F648.2 (RA3)
unnamed: 4.2, F648.4 (RA5/!MCLR!/VPP), PICKIT^.1
unnamed: 6.2, C6.1, F648.7 (RB0)
unnamed: JP2.3, RX.1
unnamed: 8.2, C8.1, F648.12 (RB5)
unnamed: 10.2, F648.3 (RA4)
unnamed: 11.2, F648.10 (RB3)
unnamed: 12.1, Q2.3 (C)
unnamed: 12.2, 13.2, Q1.1 (B)
unnamed: C3.1, G1.1, G2.1, LM386.8 (GAIN)
unnamed: 1.2, 6.1, SV2.3
unnamed: 2.2, 7.1, SV2.2
unnamed: 3.2, 8.1, SV2.1
unnamed: JP2.2, TX.1
unnamed: 17.1, F648.19 (RA0)
unnamed: 18.1, F648.20 (RA1)
unnamed: 7.2, C7.1, F648.11 (RB4), PICKIT^.6
unnamed: F648.9 (RB2), TX.2
unnamed: F648.14 (RB7), PICKIT^.4
unnamed: F648.8 (RB1), RX.2
unnamed: F648.13 (RB6), PICKIT^.5
unnamed: R22.2, SJ3.2
unnamed: 10.1, SJ1.1
unnamed: 18.2, RED.A
unnamed: 17.2, GREEN.A
unnamed: 5.1, SJ1.3
unnamed: C9.1, F648.17 (RA6), MC-306.1
unnamed: C1.2, LM386.3 (+IN)
unnamed: C11.1, LM386.5 (OUT)
unnamed: C10.1, F648.18 (RA7), MC-306.4 (2)
unnamed: C11.2, PIEZO.1 (+), R17.2
unnamed: LED.A, R22.1
unnamed: 11.1, C1.1, SJ1.2
VCC: 13.1, 78L05.3 (INPUT), C2.1, JP9.P$1, Q1.3 (E)
VDD: 1.1, 2.1, 3.1, 4.1, 78L05.1 (OUTPUT), ..1, ..2, ..3, C4.1, C13.1, F648.15 (VDD), F648.16 (VDD), PICKIT^.2, SJ3.3, SV2.4
VS: C5.1, LM386.6 (VS), Q1.2 (C), SJ3.1

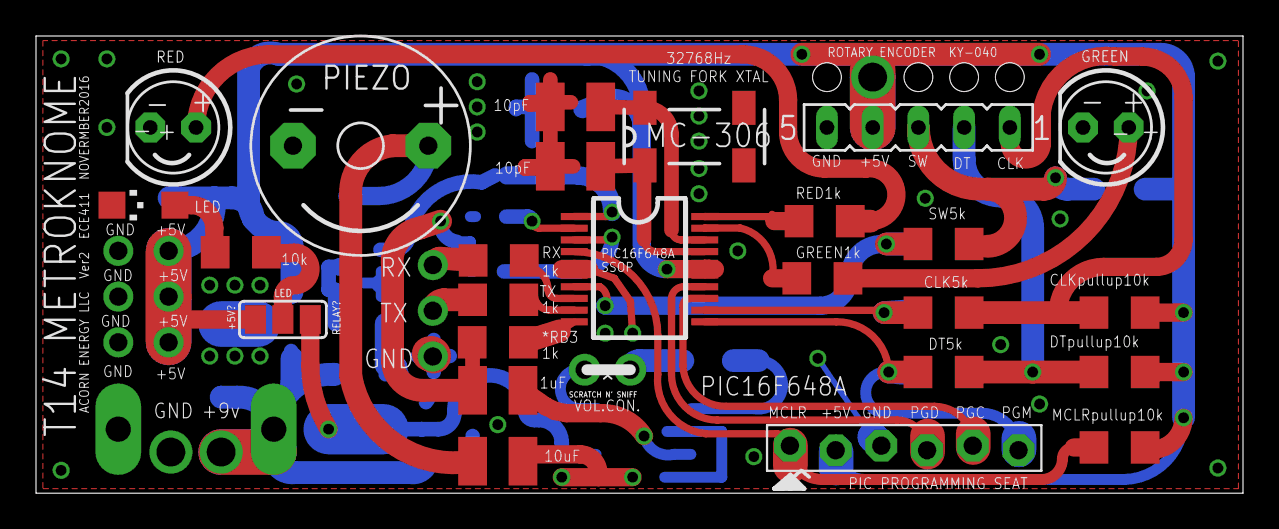
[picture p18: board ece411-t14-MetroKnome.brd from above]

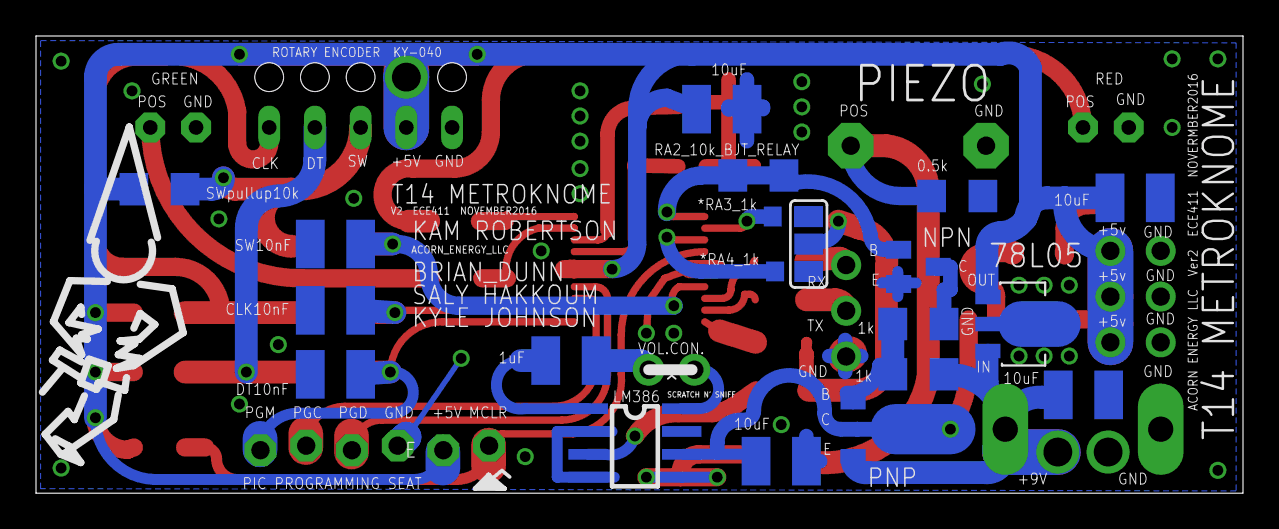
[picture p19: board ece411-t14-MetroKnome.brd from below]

Board: 2 copper layers, 67.1 x 25.4 mm, 52 parts (24 on the bottom side), 40 nets.

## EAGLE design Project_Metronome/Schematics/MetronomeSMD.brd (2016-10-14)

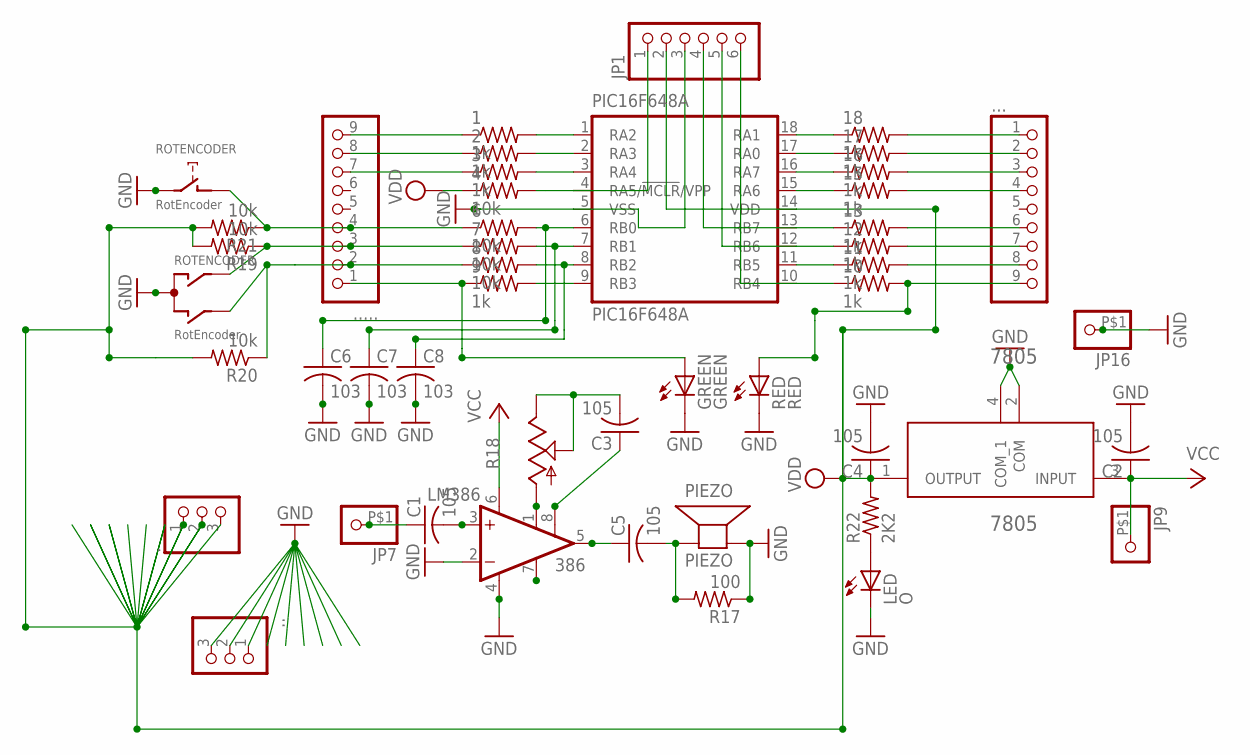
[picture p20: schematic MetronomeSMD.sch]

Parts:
1, 2, 3, 9, 10, 11, 12, 13, 15, 16, 17, 18: 1k; R1206
4, 6, 7, 8: 10k; R1206
7805: 7805; SOT150P400X160-4N
., ..: PINHD-1X3CB; 1X03-CLEANBIG
..., .....: PINHD-1X9; 1X09-BIG
C1, C2, C3, C4, C5: 105; C1210
C6, C7, C8: 103; C1210
GREEN: GREEN; LED5MM
JP1: PINHD-1X6LOCK; 1X06-BIGLOCK
JP7, JP9, JP16: PINHD-1X1-BIGPOGO; 1X1-BIGPOGO
LED: O; CHIPLED_1206
LM386: 386; SO08
PIC16F648A: PIC16F648A; DIL18
PIEZO: PIEZO; PS12
R17: 100; R1206
R18: TRIM_US-RJ9W; RJ9W
R19, R20, R21: 10k; R1206
R22: 2K2; R1206
RED: RED; LED5MM
ROTENCODER: RotEncoder; ALPS_EC12E_SW

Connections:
GND: 7805.2 (COM), 7805.4 (COM_1), ...1, ...2, ...3, C2.2, C4.2, C6.2, C7.2, C8.2, GREEN.K (C), JP1.3, JP16.P$1, LED.C, LM386.2 (-IN), LM386.4 (GND), PIC16F648A.5 (VSS), PIEZO.P$2 (-), R17.1, RED.K (C), ROTENCODER.C, ROTENCODER.E (2)
unnamed: 9.2, PIC16F648A.9 (RB3)
unnamed: 1.2, PIC16F648A.1 (RA2)
unnamed: 2.2, PIC16F648A.2 (RA3)
unnamed: 3.2, PIC16F648A.3 (RA4)
unnamed: 4.2, JP1.1, PIC16F648A.4 (RA5/!MCLR!/VPP)
unnamed: 6.2, C6.1, PIC16F648A.6 (RB0)
unnamed: 7.2, C7.1, PIC16F648A.7 (RB1)
unnamed: 8.2, C8.1, PIC16F648A.8 (RB2)
unnamed: 1.1, ......9
unnamed: 2.1, ......8
unnamed: 3.1, ......7
unnamed: 6.1, ......4, R21.1, ROTENCODER.D (1)
unnamed: 7.1, ......3, R19.1, ROTENCODER.A
unnamed: 8.1, ......2, R20.1, ROTENCODER.B
unnamed: 9.1, ......1, GREEN.A
unnamed: 18.1, PIC16F648A.18 (RA1)
unnamed: 17.1, PIC16F648A.17 (RA0)
unnamed: 16.1, PIC16F648A.16 (RA7)
unnamed: 15.1, PIC16F648A.15 (RA6)
unnamed: 13.1, JP1.4, PIC16F648A.13 (RB7)
unnamed: C3.1, LM386.8 (GAIN)
unnamed: 12.1, JP1.5, PIC16F648A.12 (RB6)
unnamed: LM386.1 (GAIN), R18.A
unnamed: 11.1, PIC16F648A.11 (RB5)
unnamed: 10.1, JP1.6, PIC16F648A.10 (RB4)
unnamed: 18.2, ....1
unnamed: 17.2, ....2
unnamed: 16.2, ....3
unnamed: 15.2, ....4
unnamed: 13.2, ....6
unnamed: C3.2, R18.E, R18.S
unnamed: 12.2, ....7
unnamed: C1.2, LM386.3 (+IN)
unnamed: C5.1, LM386.5 (OUT)
unnamed: 11.2, ....8
unnamed: 10.2, ....9, RED.A
unnamed: C5.2, PIEZO.P$1 (+), R17.2
unnamed: LED.A, R22.1
unnamed: C1.1, JP7.P$1
VCC: 7805.3 (INPUT), C2.1, JP9.P$1, LM386.6 (VS)
VDD: 4.1, 7805.1 (OUTPUT), ..1, ..2, ..3, C4.1, JP1.2, PIC16F648A.14 (VDD), R19.2, R20.2, R21.2, R22.2

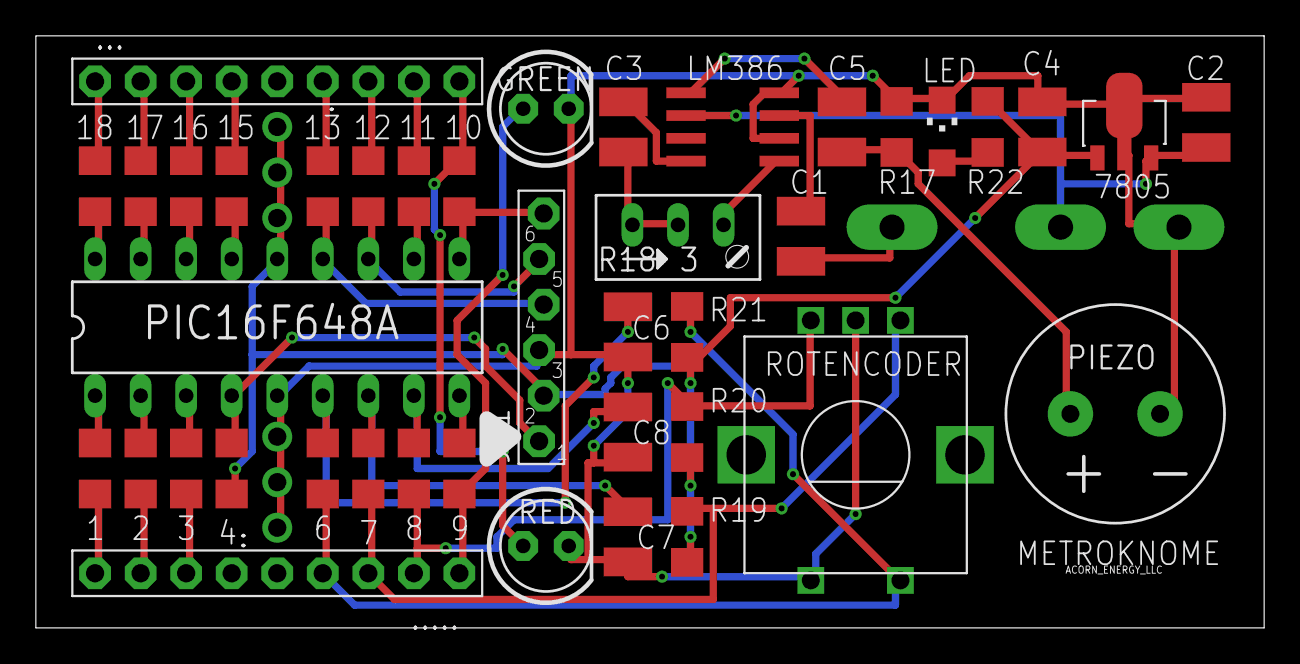
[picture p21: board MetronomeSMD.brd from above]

Board: 2 copper layers, 68.5 x 33.0 mm, 46 parts (0 on the bottom side), 42 nets.

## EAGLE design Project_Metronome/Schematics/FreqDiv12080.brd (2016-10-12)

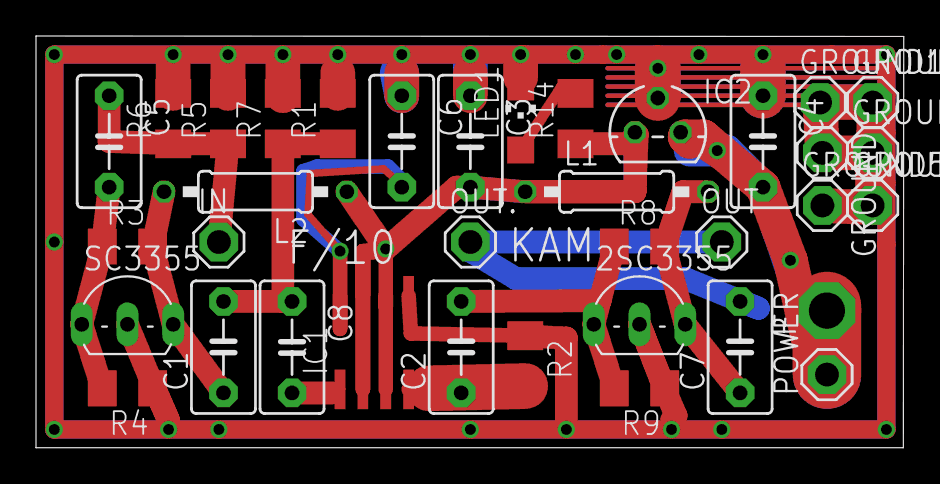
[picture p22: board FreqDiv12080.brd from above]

Board: 2 copper layers, 48.2 x 22.9 mm, 36 parts (0 on the bottom side), 14 nets.

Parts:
2SC3355: TO92-BEC
C1, C2, C5, C6, C7, C8: 1nF; C5B3.5
C3, C4: 1uF; C5B3.5
GROUND, GROUND1, GROUND2, GROUND3, GROUND4, GROUND5: SE13
IC1: MC12080D; SO08
IC2: 78L05Z; TO92
IN: SE13
L1, L2: 1mH; 0207/10
LED1: CHIPLED_1206
OUT, OUT.: SE13
P: TPPAD1-20; P1-20
POWER: SE13
R1, R5, R6, R7: 100; M1206
R2: 820; M1206
R3, R8: 10k; M1206
R4, R9: 3k3; M1206
R14: 1k; M1206
SC3355: TO92-BEC

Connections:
unnamed: C4.2, IC2.3, P.TP, POWER.MP
unnamed: C2.1, IC1.4, R2.2
unnamed: 2SC3355.B, C2.2, R8.1, R9.2
unnamed: C3.2, IC1.2, IC1.3, IC1.6, IC1.7, IC2.1, L1.1, L2.1, R14.1
unnamed: C5.1, IN.MP, R5.1, R6.1
unnamed: C5.2, R3.1, R4.2, SC3355.B
unnamed: C7.2, OUT.MP, OUT..MP
unnamed: 2SC3355.C, C7.1, L1.2, R8.2
unnamed: LED1.A, R14.2
unnamed: C6.2, IC1.8
unnamed: C1.2, C8.1, R1.1, R7.1
unnamed: 2SC3355.E, C3.1, C4.1, C6.1, GROUND.MP, GROUND1.MP, GROUND2.MP, GROUND3.MP, GROUND4.MP, GROUND5.MP, IC1.5, IC2.2, LED1.C, R1.2, R2.1, R4.1, R5.2, R6.2, R7.2, R9.1, SC3355.E
unnamed: C8.2, IC1.1
unnamed: C1.1, L2.2, R3.2, SC3355.C

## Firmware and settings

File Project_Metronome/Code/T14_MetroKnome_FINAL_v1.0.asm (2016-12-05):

;********************************************************************************
; DOES IT WORK?		YES!!!
; FILENAME:			T14_MetroKnome_Final_V1.0
; VERSION:			1.0
; DATE:				30 NOV 2016	
; FILE SAVED AS:	T14_MetroKnome_Final_V1.0.asm
; MICROCONTROLLER:	PIC16F648A
; CLOCK FREQUENCY:	32kHz using the on-board(ext) oscillator for battery life
;********************************************************************************
; FILES REQUIRED:  	p16f648a.inc
;********************************************************************************
; PROGRAM FUNCTION:	METROKNOME 
;		THIS CODE IS FOR FINAL OPERATION		
;********************************************************************************
; HOUSEKEEPING
	list p=16f648a		; list directive to define processor
	include C:\Program Files (x86)\Microchip\MPLABX\v3.45\mpasmx\p16f648a.inc	
	 ; '__CONFIG' directive is used to embed configuration word within .asm file
		__CONFIG _FOSC_LP & _WDTE_OFF & _PWRTE_OFF & _MCLRE_OFF & _BOREN_OFF & _LVP_OFF & _CPD_OFF & _CP_OFF
;================================================================================
; DECLARATIONS cpu equates (memory map)
TMR0	EQU	0x01		; Timer0 Module Register
porta	EQU	0x05		; assigns the memory location of register PORTA to porta for use in code 
PORTA	EQU	0x05		; literals assigned with EQU cannot be changed elswhere in code
PORTB	EQU	0x06		; creates an un-changable pointer and allows use of lower case porta
portb	EQU	0x06		; allows use of lower case PORTB
state	EQU	0x21		; stores current lighting state
tic_rt	EQU	0xFC		; variable for tic rate. ~10ms
work	EQU	0x23		; interrupt service temporarilly stores working register here
stat	EQU	0x24		; interrupt service temporarilly stores status register here
oldstate    EQU 0x25		; register to store encoder prior state
newstate    EQU 0x26		; register to store register current state
rate	EQU 0x27		; register to store encoder rate to pass to timer
w_temp  EQU     0x71        	; variable used for context saving 
status_temp EQU     0x72        ; variable used for context saving
pclath_temp EQU     0x73        ; variable used for context saving
; DECLARATIONS bit equates
w	EQU 0			; allows for use of "w" =working register instead of zero for the destination
f	EQU 1			; allows for use of "f" =file instead of one for the destination
;()()()()()()()()()()()()()()()()()()()()()()()()()()()()()()()()()()()()()()()()
;()()()()()()()()()()()()()()()()()()()()()()()()()()()()()()()()()()()()()()()()
; START
	ORG	0x00
	GOTO	start
	ORG	0x04
	GOTO	intserv
	
start
	CALL	initializer
	GOTO	main

main	
	NOP

	GOTO 	main

;()()()()()()()()()()()()()()()()()()()()()()()()()()()()()()()()()()()()()()()()
;()()()()()()()()()()()()()()()()()()()()()()()()()()()()()()()()()()()()()()()()


;*********************************************************************************
	; Subroutines and Functions
;*********************************************************************************

intserv
;---------------------------------------------------------
	
	;Push registers to store current state before interrupt
		movwf   w_temp            		; save off current W register contents
		movf	STATUS,w          		; move status register into W register
		movwf	status_temp       		; save off contents of STATUS register
		movf	PCLATH,w          		; move pclath register into W register
		movwf	pclath_temp       		; save off contents of PCLATH register
	;Check Timer
		BTFSC	INTCON, 2			; Timer0 interrupt flag
		GOTO 	timer_svc	
	;Check Button(PORTB:0)
		BTFSC	INTCON,	1			; RB0 Interrupt flag			
		GOTO	button_svc
	;Check Encoder(PORTB:(4:5))
		BTFSC	INTCON,	0			; PORTB Interrupt flag
		GOTO	encoder_svc
		GOTO	intexit				; Must be a glitch get out and hope nobody noticed
;---------------------------------------------------------	
timer_svc
		
		BTFSS	state, 0			; Test current state
		CALL	toc				; If 0 goto 'toc'
		BTFSC 	state, 0			; If 0, return from call from previous line will skip this
		CALL 	tic				; If 1 goto 'tic'
		COMF	state, f			; Toggle state bit
		BCF	INTCON,	2			; Clear interrupt flag
		GOTO	intexit				; END TIMER_SVC
button_svc
		BCF	INTCON, 5			; Disable interrupt for Timer0
		BCF	INTCON, 1			; Clear interrupt flag
loopb		BTFSS	INTCON, 1			; Wait for button press
		GOTO	loopb				; If button not pressed keep waiting
		BCF	INTCON, 1
		BSF	INTCON, 5			; ReEnable interupt for Timer0
		GOTO	intexit				; END BUTTON_SVC
encoder_svc
		MOVF	PORTB, f			; Clears interrupt condition
		CALL	chk_encoder			; Read encoder
		BCF	INTCON, 0			; Clear interrupt flag
		GOTO	intexit				; END ENCODER_SVC

intexit
	;Pop to registers to state before interrupts
		BSF	INTCON, 5
		MOVF	rate, w			; Load UPDATED timer rate for Timer0
		MOVWF	TMR0			; Load timer rate INTO Timer0
		movf    pclath_temp,w     	; retrieve copy of PCLATH register
		movwf	PCLATH            	; restore pre-isr PCLATH register contents
		movf    status_temp,w     	; retrieve copy of STATUS register
		movwf	STATUS            	; restore pre-isr STATUS register contents
		swapf   w_temp,f
		swapf   w_temp,w          	; restore pre-isr W register contents
		RETFIE
;**************************************************************************************************************************************************
;**************************************************************************************************************************************************

initializer

; Set PORTA Tri-State. Outputs are bits PORTA:0,1,2. 	Bits PORTA:3,4,5 are input by default
;		
		CLRF	PORTA				; Set outputs to 0 FOR SAFETY
		BSF	STATUS, 5			; GO to bank 1
		BCF	TRISA, 0			; PORTA:0 IS AN OUTPUT
		BCF	TRISA, 1			; PORTA:1 IS AN OUTPUT
		BCF	TRISA, 2			; PORTA:2 IS AN OUTPUT
		BCF	STATUS, 5			; Back to Bank0

; Set PORTB Tri-State. Output is PORTB:3 		; Bits PORTB:0,1,2,4,5,6,7 are inputs by defaults
;
		CLRF	PORTB				; GO to bank 1
		BSF	STATUS, 5			
		BCF	TRISB,	3			; PORTB:3 IS AN OUTPUT
		BCF	STATUS, 5			; Bank0
;
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

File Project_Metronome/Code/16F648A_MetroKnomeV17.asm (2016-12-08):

;********************************************************************************
; DOES IT WORK?		WORKS, BUT,  ... SEE VERSION 15 FOR WORKING CODE
; FILENAME:			METROKNOME
; VERSION:			17
; DATE:				01DEC2016	
; FILE SAVED AS:	16F648A_MetroKnomeV17.asm
; MICROCONTROLLER:	PIC16F648A
; CLOCK FREQUENCY:	32.768kHz using an off-board oscillator for battery life
;********************************************************************************
; FILES REQUIRED:  	p16f648a.inc
;********************************************************************************
; PROGRAM FUNCTION:
;	It's a minimalist metronome, two lights, a buzzer, control knob, and on/off button
;	adjustable alterating led illumination and piezo sound to accompany each flash
;	rate adjustable from about 30-256 bpm in rock time.  STARTS AT 60 BPM
;********************************************************************************
; NOTES:	TRYING TO GET RID OF THE DELAY LOOP IN FAVOR OF TIMER2 PWM PIEZO
;			WORKS THE FREQUENCY AND DUTY CYCLE OF TIMER2 NEEDS TO BE DETERMINED.


;			RA0	SOURCE GREEN LED											OUTPUT
;			RA1	SOURCE RED LED												OUTPUT
;			RA2	SOURCE BJT RELAY CONTROLLING POWER TO THE OPAMP AND PIEZO	OUTPUT
;			RB0	BUTTON														INPUT
;			RB3	PIEZO BUZZER SOUND WAVE										OUTPUT
;			RB4	ROTARY ENCODER												INPUT
;			RB5	ROTARY ENCODER												INPUT
;
;
;SOMEHOW THE ORDER OF SETUP INSTRUCTIONS INTCON FIRST THEN OPTION_REG MATTERS
;IT WORKS AS THIS IS WRITTEN
;I WANT TO KNOW WHY WHY WHY!!!!!!!!!!!!!!!
;
;	? RA4 can only sink power (no led sourcing?)
;
;********************************************************************************
; AUTHOR:			KAM ROBERTSON
; COMPANY:			ACORN ENERGY LLC
;********************************************************************************
;********************************************************************************
;********************************************************************************
; HOUSEKEEPING
    list p = 16f648a		; list directive to define processor
    include C:\Program Files (x86)\Microchip\MPASM Suite\p16f648a.inc	
    __CONFIG   _CP_OFF & _CPD_OFF & _LVP_OFF & _BOREN_OFF & _MCLRE_ON & _PWRTE_ON & _WDT_OFF & _LP_OSC           
	; PIC15F648A internal 4mhz oscillator
	; '__CONFIG' directive is used to embed configuration word within .asm file
;================================================================================
; DECLARATIONS cpu equates (memory map)
porta	EQU	0x05	; assigns the memory location of register PORTA to porta for use in code 
					; literals assigned with EQU cannot be changed elswhere in code
					; creates an un-changable pointer and allows use of lower case porta
portb	EQU	0x06	; allows use of lower case PORTB
;
; DECLARATIONS bit equates
num0	EQU	0x20	; "num0" is a pointer to register 32
num1	EQU	0x21	; "num1" is a pointer to register 33
num2	EQU	0x22	; "num2" is a pointer to register 34
work	EQU	0x23	; interrupt service temporarilly stores working register here
stat	EQU	0x24	; interrupt service temporarilly stores status register here
speed	EQU	0x25	; use for timer inc/dec that is used to run the led's and piezo buzzer
d1		equ	0x26	; determines time spent in the delay loop
duty1	equ	0x27	; used for pwm prescaler
duty2	equ	0x28	; used for pwm prescaler
ledstate	equ	0x29	; led ledstate green-set or red-clear
mute	equ	0x2A	; allows sound to be muted or not every other on/off cycle
roten	equ	0x2B	; quadrature
tone1	equ	0x2C	; quadrature
past	equ	0x2D	; quadrature
present	equ	0x2E	; quadrature
time	equ	0x2F	; used to set the beat tone sent to the piezo.  increments every light cycle
beatstate	equ	0x30	; use logic shift and bit test to set the beat time beatstate: mute, 4/4, 2/4, 2/3, 3/4. 6/4 
d2		equ	0x31	; determine time spent in the delay loop
;================================================================================
; PROGRAM STARTS BELOW
    ORG		0x000
    GOTO	start	; go to the start 
    ORG		0x004	; interrupt service vector at memory location 0x004 it goes here automatically when intcon bit-1 is set
    GOTO	intserv	; go to the interrupt service function
start
    CALL initializer	; CALL the function "initializer"
    goto main
	;
	;
main
	
;	goto	fourfour
;
	btfsc	beatstate,	0
	goto	zerofour
	;
	btfsc	beatstate,	1
	goto	mutefour
	;
	btfsc	beatstate,	2
	goto	fourfour
	;
	btfsc	beatstate,	3
	goto	twofour
	;
	btfsc	beatstate,	4
	goto	threefour
	;
	btfsc	beatstate,	5
	goto	twothree
	;
	btfsc	beatstate,	6
	goto	sixfour
	;
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

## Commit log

2016-10-12 FAB SHOP
    EagleCAD diagram and schematic submitted as a test board to OshPark
    I expect the pcb's by 24OCT2016
    [FreqDiv12080.brd, FreqDiv12080.sch]
2016-10-12 Dev. Board Components
2016-10-12 Rotary encoder
    I am working on setting one of these up for use on the dev board.
    The knob push button will operate the interrupt pin
    The rotating knob uses two pins to control slower/faster in digital increments
2016-10-12 FUN PICTURES
    rough proto circuit.... no enclosure dimensions, likely spelling errors, pins not declared---- except for the rotary encoder, those are good pins.
    The pictures are from OshPark showing what our PCB could look like for evaluation.
    [MetronomeSMD.brd, MetronomeSMD.sch]
2016-10-12 better eagle files
    [MetronomeSMD.brd, MetronomeSMD.sch]
2016-10-12 better eagle files
    the traces are auto trash and there is a lot of "extra parts", but the form is coming together. Width is close to the size of enclosures I am investigating. The short dimension can still be shrunk further. Currently this plan is about $18 at OshPark for three boards. That's OK.
    [MetronomeSMD.brd]
2016-10-13 Schematics
    placeholder for schematics
2016-10-13 Rename Project_Metronome/FreqDiv12080.brd to Project_Metronome/Schematic/FreqDiv12080.brd
    Moved to Schematic folder
    [FreqDiv12080.brd]
2016-10-14 Corrected names and pull up added to MCLR
    [MetronomeSMD.brd, MetronomeSMD.sch]
2016-10-31 BOM snd COST
    [DevBoard_BOM_14_MetroKnome.xlsx, PCB_BOM_14_MetroKnome.xlsx]
2016-11-03 Board and Diagram
    v4MetroKnome submitted to OshPark
    v4_1MetroKnome is nearing completion for 17NOV16 submittal
    [v4MetroKnome.brd, v4MetroKnome.sch, v4_1MetroKnome.brd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]
2016-11-07 Current PCB
    board and diagram with oshpark generated pictures
    [T14_V2_METROKNOME.brd, T14_V2_METROKNOME.sch]
2016-11-13 FINISHED PCB
    FAB SHOP ON THE 17th
    [ece411-t14-MetroKnome.brd, ece411-t14-MetroKnome.sch]
2016-11-20 Current cost estimate and bom
    $
    [T14_METROKNOME_TotalBOM.xlsx]
2016-11-23 Add files via upload
    Test program to test encoder funtionality
2016-11-23 Add files via upload
    Test script for rotary encoder, Lights will indicate state of encoder output. Push button goes to interrupt procedure which will indicate an increment or decrement from encoder.
2016-11-23 Add files via upload
    MetroKnome Program Flow Chart
2016-11-30 PWM code
2016-12-01 Proto_01
    Initial prototype board
2016-12-01 final_solution_02_top_view
    top view of finished product in case
2016-12-01 final_solution_03
    top view with case cover removed
2016-12-04 moved decision matrix to homework folder
    [DecisionMatrixTemplate_ECE411.xlsx]
2016-12-04 LTspice schematic capture
    During development phase of design (Oct 2016)
2016-12-04 moved LTspice schematic to appropriate directory
2016-12-05 Add files via upload
    Final version. Fixed linearity with encoder rate tic_rate was adjusted to slightly less than 10ms.
    [T14_MetroKnome_FINAL_v1.0.asm]
2016-12-05 Update T14_MetroKnome_FINAL_v1.0.asm
    Comments fixes
    [T14_MetroKnome_FINAL_v1.0.asm]
2016-12-07 board layout image
2016-12-08 Update to test plan
    added test_cases to verify functionality of rotary encoder
2016-12-08 PWM mode initial notes
